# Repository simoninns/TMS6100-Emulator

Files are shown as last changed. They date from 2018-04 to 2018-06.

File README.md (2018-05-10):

## Synopsis

TMS6100 speech PHROM (PHrase Read Only Memory) hardware emulator for use with the TMS5220 Voice Synthesis Processor in an Acorn BBC Microcomputer

## Motivation

This project creates a TMS6100 speech PHROM (PHrase Read Only Memory) for use with the TMS5220 Voice Synthesis Processor in an Acorn BBC Microcomputer. Whilst it’s still possible to purchase TMS5220 ICs from sites like Ebay, the TMS6100 was a mask-programmed ROM that Acorn produced specifically for their speech upgrade and is therefore difficult and expensive to source. Instead of using the original ROM, this project uses an ATmega32U2 microcontroller to both emulate the ROM and provide the original Acorn voice sample data recorded by BBC newsreader Kenneth Kendall.

## Installation

Note: This is an Atmel Studio 7 project that can be loaded and compiled by the IDE

Please see http://www.waitingforfriday.com/?p=30 for detailed documentation about TMS6100-Emulator

The PHROM data for both the Acorn Speech System PHROM and the American TI PHROM is included in the source-code.  By default it will compile using the Acorn Speech Data.  Specifying the compiler macro PHROM_ACORN selects the Acorn PHROM and PHROM_US selects the American PHROM.  Note that the American PHROM is not generally for use with the BBC Micro and is included for experimental use (or use in other microcomputer systems).

## Author

TMS6100-Emulator is written and maintained by Simon Inns.

## License (Software)

    TMS6100-Emulator is free software: you can redistribute it and/or modify
    it under the terms of the GNU General Public License as published by
    the Free Software Foundation, either version 3 of the License, or
    (at your option) any later version.

    TMS6100-Emulator is distributed in the hope that it will be useful,
    but WITHOUT ANY WARRANTY; without even the implied warranty of
    MERCHANTABILITY or FITNESS FOR A PARTICULAR PURPOSE.  See the
    GNU General Public License for more details.

    You should have received a copy of the GNU General Public License
    along with TMS6100-Emulator. If not, see <http://www.gnu.org/licenses/>.

## License (Hardware)

Both the schematic and the PCB design of TMS6100-Emulator are covered by a Creative Commons license; as with the software you are welcome (and encouraged!) to extend, re-spin and otherwise use and modify the design as allowed by the license.  However; under the terms of the Attribution-ShareAlike 4.0 International (CC BY-SA 4.0) license you are required to release your design (or redesign) under the same license.  For details of the licensing requirements please see <https://creativecommons.org/licenses/by-sa/4.0/>

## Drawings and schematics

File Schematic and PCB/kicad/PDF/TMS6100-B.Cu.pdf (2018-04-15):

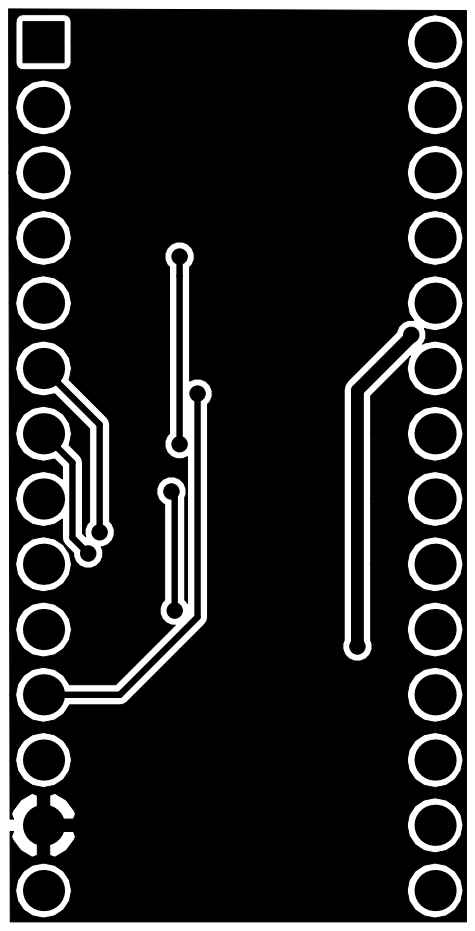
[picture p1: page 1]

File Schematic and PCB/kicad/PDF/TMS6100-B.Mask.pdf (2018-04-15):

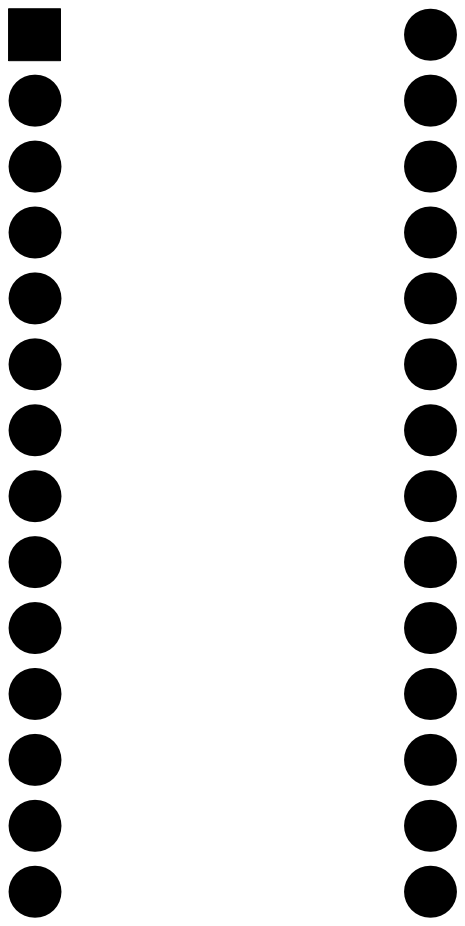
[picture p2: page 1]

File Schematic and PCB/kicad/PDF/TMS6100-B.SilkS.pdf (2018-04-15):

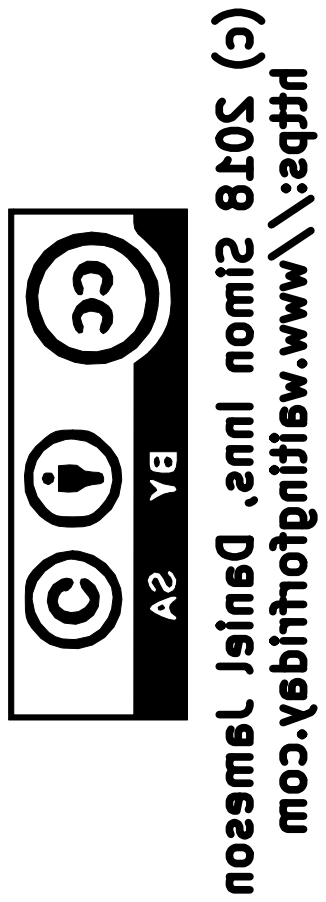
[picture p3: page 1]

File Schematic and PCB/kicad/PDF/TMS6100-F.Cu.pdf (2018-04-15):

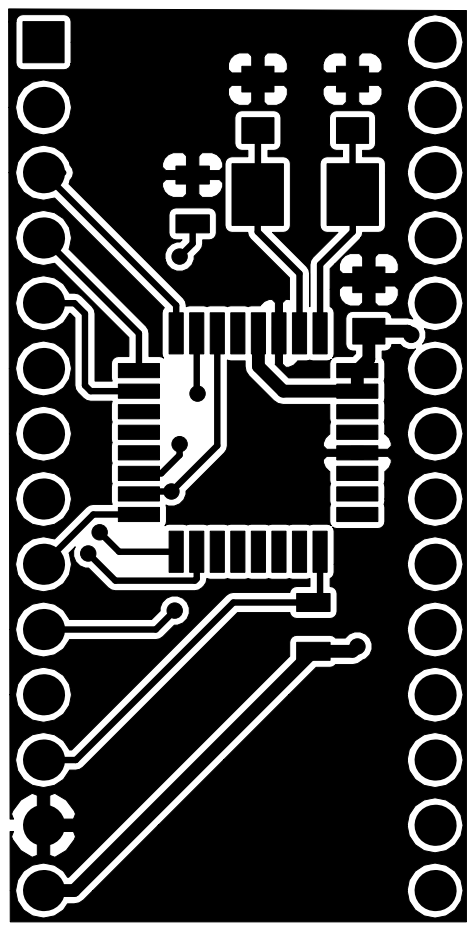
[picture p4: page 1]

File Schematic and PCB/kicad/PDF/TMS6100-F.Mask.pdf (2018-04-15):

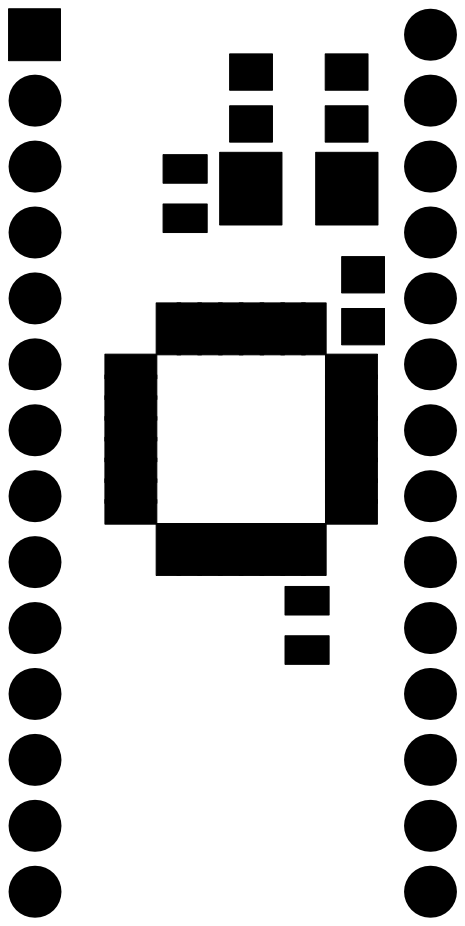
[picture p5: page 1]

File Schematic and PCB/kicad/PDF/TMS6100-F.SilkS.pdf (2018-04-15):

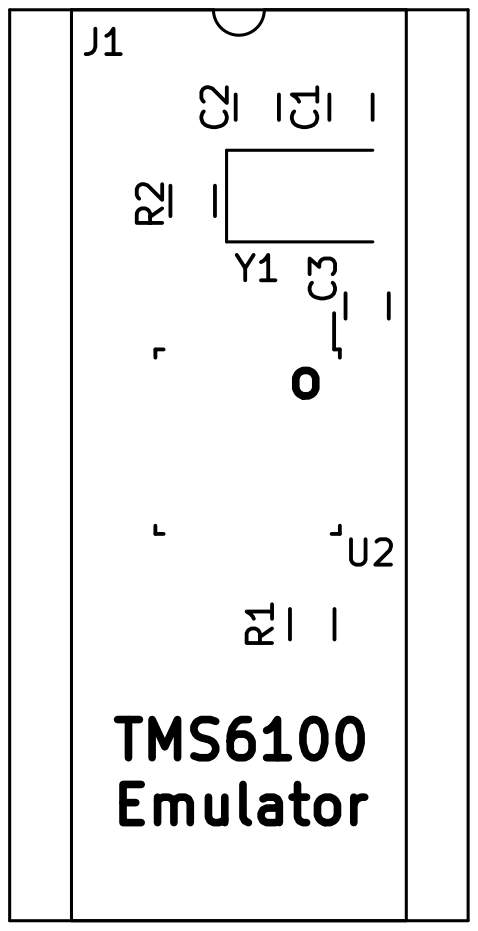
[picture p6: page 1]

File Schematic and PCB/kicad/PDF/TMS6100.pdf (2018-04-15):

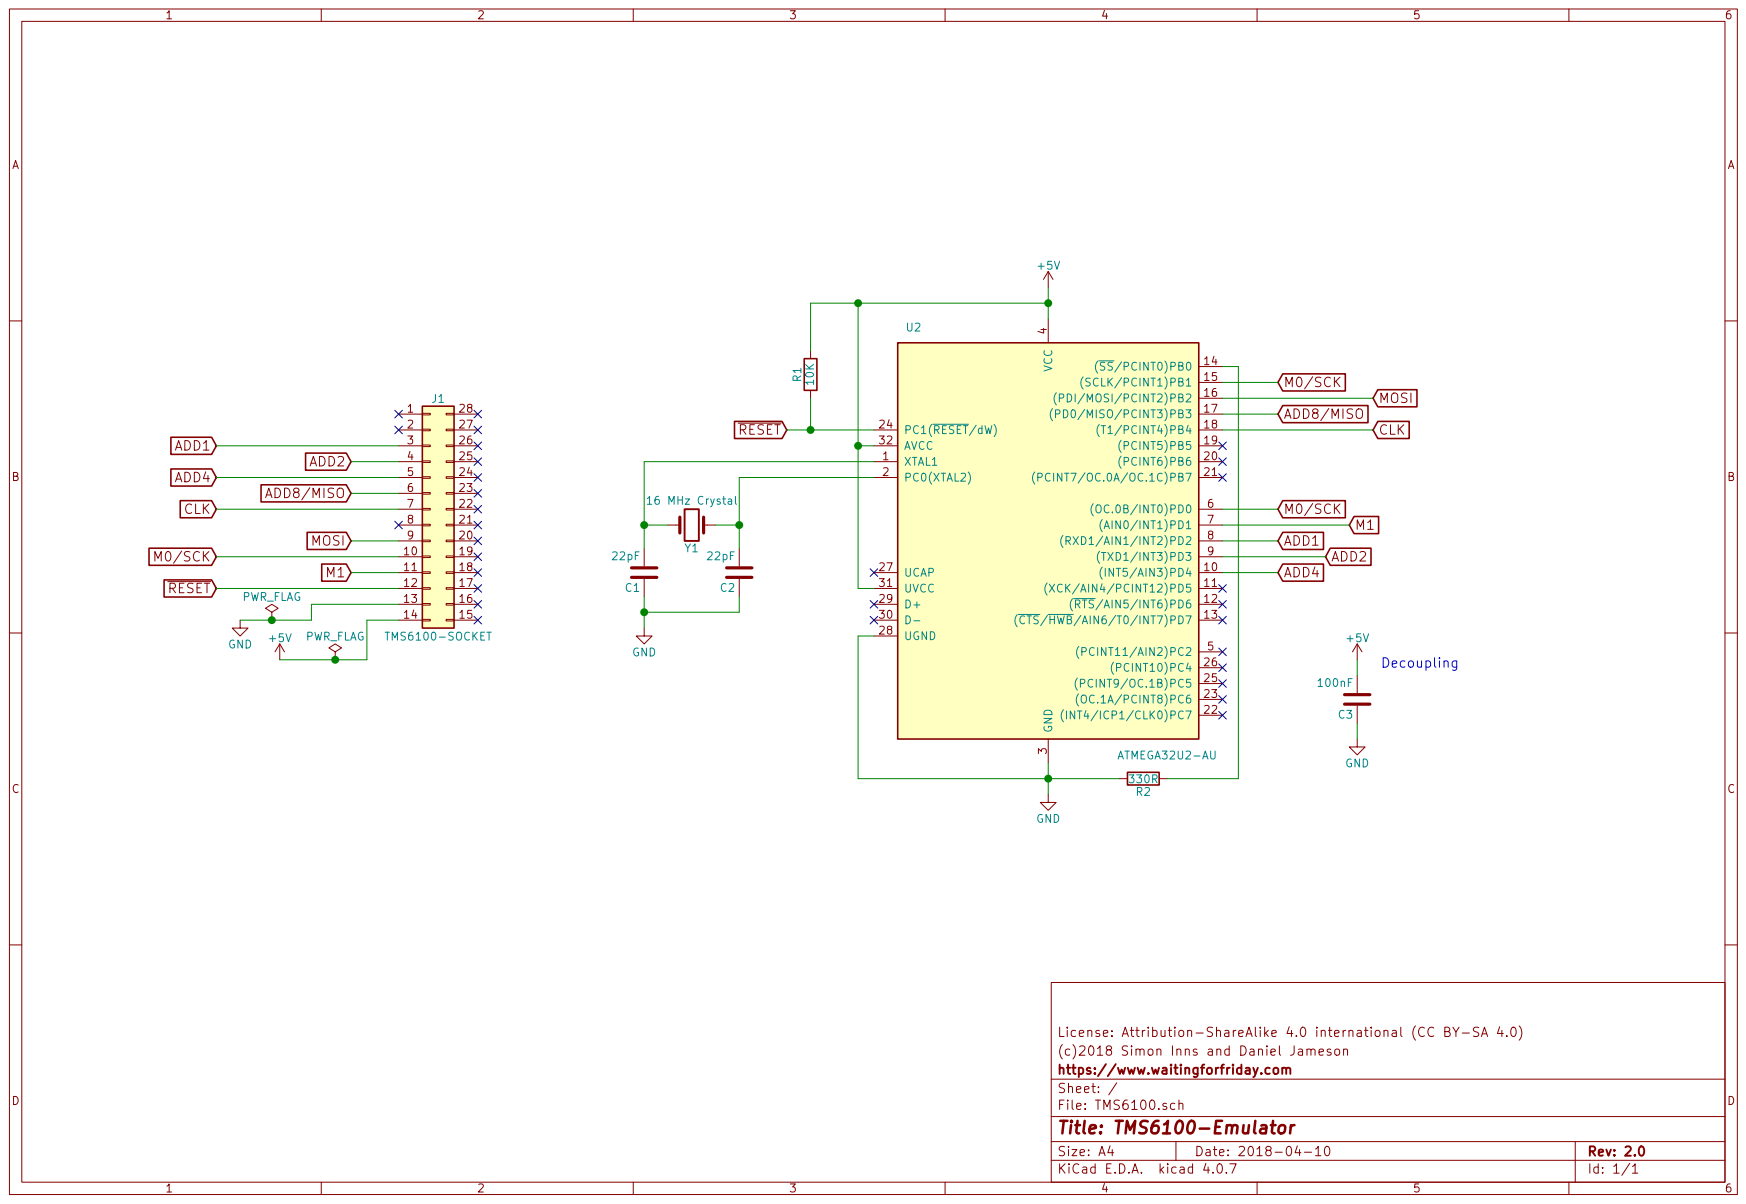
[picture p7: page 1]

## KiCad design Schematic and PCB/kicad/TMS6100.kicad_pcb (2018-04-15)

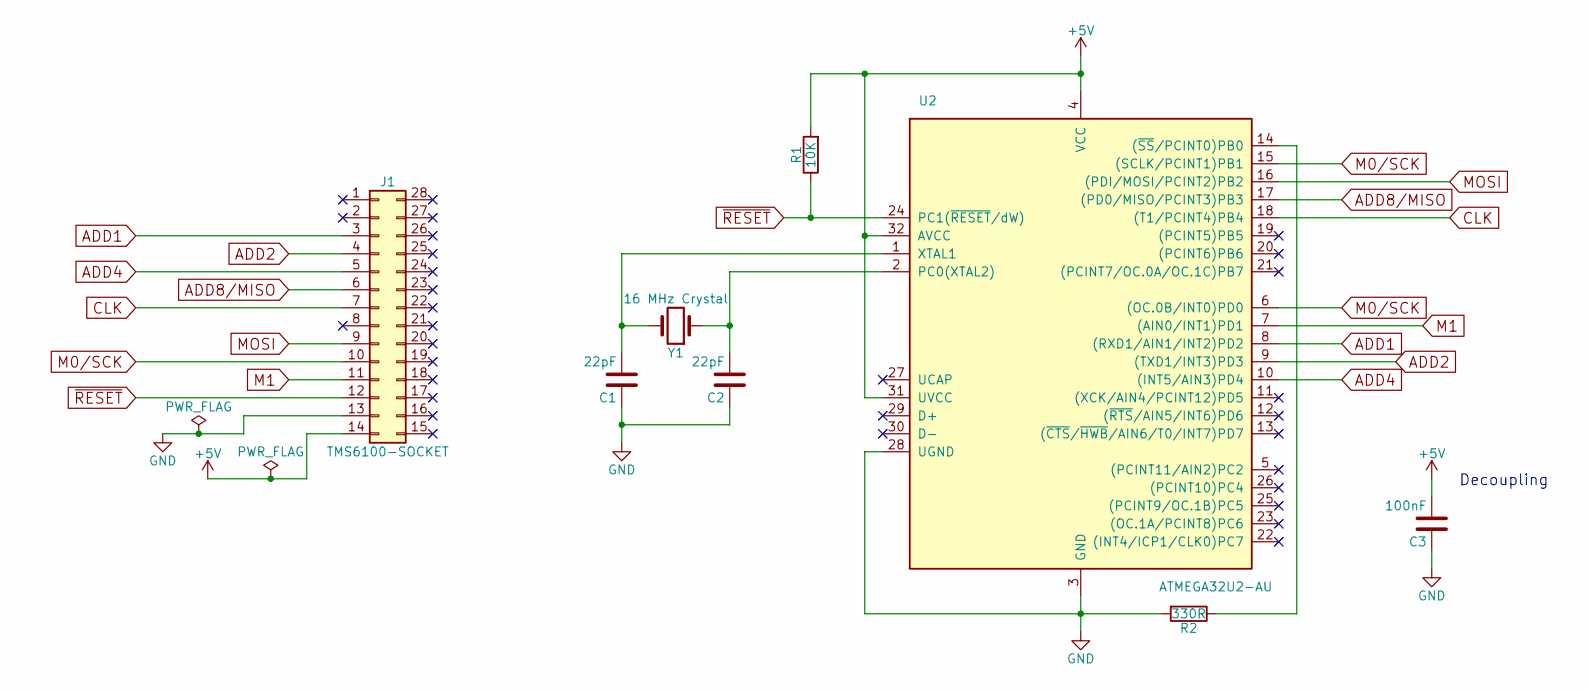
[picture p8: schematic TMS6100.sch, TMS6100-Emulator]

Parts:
C1, C2: 22pF; C_0805
C3: 100nF; C_0805
J1: TMS6100-SOCKET; DIP-28_W15.24mm_Socket
R1: 10K; R_0805
R2: 330R; R_0805
U2: ATMEGA32U2-AU; TQFP-32_7x7mm_Pitch0.8mm
Y1: 16 MHz Crystal; Crystal_SMD_5032-2pin_5.0x3.2mm

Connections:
+5V: C3.2, J1.14, R1.2, U2.4 (VCC), U2.31 (UVCC), U2.32 (AVCC)
ADD1: J1.3, U2.8 ((RXD1/AIN1/INT2)PD2)
ADD2: J1.4, U2.9 ((TXD1/INT3)PD3)
ADD4: J1.5, U2.10 ((INT5/AIN3)PD4)
ADD8/MISO: J1.6, U2.17 ((PD0/MISO/PCINT3)PB3)
CLK: J1.7, U2.18 ((T1/PCINT4)PB4)
GND: C1.1, C2.1, C3.1, J1.13, R2.2, U2.3 (GND), U2.28 (UGND)
M0/SCK: J1.10, U2.6 ((OC.0B/INT0)PD0), U2.15 ((SCLK/PCINT1)PB1)
M1: J1.11, U2.7 ((AIN0/INT1)PD1)
MOSI: J1.9, U2.16 ((PDI/MOSI/PCINT2)PB2)
unnamed: C1.2, U2.1 (XTAL1), Y1.2
unnamed: C2.2, U2.2 (PC0(XTAL2)), Y1.1
unnamed: R2.1, U2.14 ((~SS~/PCINT0)PB0)
~RESET: J1.12, R1.1, U2.24 (PC1(~RESET~/dW))

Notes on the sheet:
Decoupling

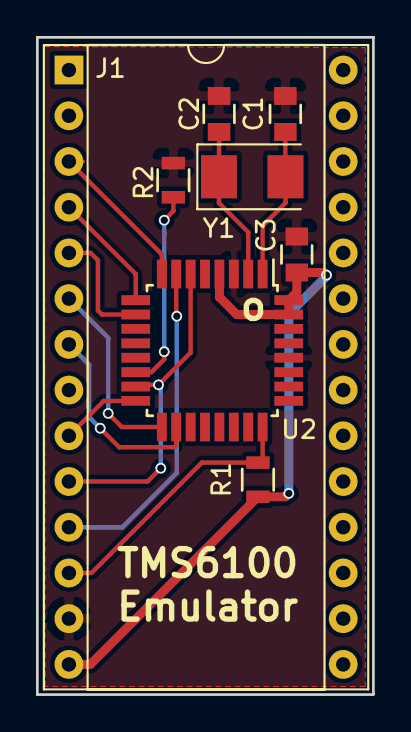
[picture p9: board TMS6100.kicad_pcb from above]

Board: 2 copper layers, 18.7 x 36.5 mm, 8 parts (0 on the bottom side), 14 nets.

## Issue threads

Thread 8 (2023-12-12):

Use on a TI-99/4A

shift838, 2023-12-12:
I am curious if this can be used on a TI-99/4A computer.

the PHROM data on the TI was split into 2 TMS6100 ICs that were piggy backed on the unit.  I have the actual dump of the PHROMs but how would I get this to work?

simoninns, 2023-12-12:
There isn't enough flash RAM available in the AVR to hold two PHROM data images; so the only way would be to piggy-back two emulator boards (or redesign one with a bigger AVR).  I've never looked into the multi-ROM operation, so I'm not sure what would happen next but, the information is most likely in the datasheet.  You would need to get this all set up with the TI-99/4A and test - the current design was specifically developed for the Acorn BBC Micro - so there are likely to be some differences in what's required.

shift838, 2023-12-12:
How did you get the BBC Micro PHROM data into the .h file?  I would need to do the same for each of my PHROM dumps.  My dumps are raw dumps for the TI.

simoninns, 2023-12-12:
The images of the data were already available online... I just used some random tool to convert them into the C language hex blocks and included them in a header file.

shift838, 2023-12-12:
can you point me to the original images of the PHROM for the bbc micro so I can compare and if you can remember what tool you used to convert.

simoninns, 2023-12-12:
The original images are just bytes in a file dumped from the PHROM... exactly the data that's included in the current project (I'm sure some googling will find other dumps of the PHROMs if you need them) - but there is nothing really to 'compare'.  As for the tool... it was a good few years ago... but writing a simple C program to read a byte stream and output hex values as text is just a few lines of code.

You can find some more detail about how the PHROM works here:

https://www.waitingforfriday.com/?p=30

shift838, 2023-12-12:
There are online converters that will also convert the binary to hex, like https://tomeko.net/online_tools/file_to_hex.php?lang=en

Also I was reading that the !CS pin has to be tied to ground since the original TMS6100 was powered by -5v.  is that correct, is that the only change that needs to happen?  Or does the circuit board for the 6100 Emulator already do that?

simoninns, 2023-12-13:
In the emulator implementation the !CS pin (13) is used to source 0V GND (look at the available schematics).  This is because the original was +5V and -5V supplied - which cannot be supported by the AVR microcontroller without additional components.

https://github.com/simoninns/TMS6100-Emulator/blob/master/Schematic%20and%20PCB/kicad/PDF/TMS6100.pdf

shift838, 2024-01-16:
what tool did you use to compile this firmware into a hex file?

shift838, 2024-01-17:
I was able to get it compiled with Atmel Studio 7.

shift838, 2024-01-18:
a few more questions:

1. Does the hex file generated already have the bootloader imbedded or do you need to write a bootloader to the ATMEGA32U2 ?
2. What programmer are you using to write the bootloader and/or hex to the ATMEGA32U2 chip?
3. If you need to update the code on the TMS6100 emulator board after it is built how are you doing that?

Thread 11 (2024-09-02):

Programming questions

shift838, 2024-09-02:
I have built the TMS6100 and want to use it for another retro computer (TI-99/4A) that actually use 2 TMS6100 piggy backed.  I have dump my ROMS for the speech and will need to program 2 TMS6100 emulator chips.

My question is I have burned a boot loader using the below command on both tms6100 emulator chips:
avrdude -vvv -c USBasp -p m32u2 -u -U flash:w:d:\speech\roms\BL_atmega32u2.hex:i

The above is a boot loader.  I then burn the appropriate speech ROM into each one:
avrdude -vvv -c USBasp -p m32u2 -u -U flash:w:d:\speech\roms\CD2325A.hex:i

replace with the second chip and issue command:
avrdude -vvv -c USBasp -p m32u2 -u -U flash:w:d:\speech\roms\CD2326A.hex:i

Both go with no issues but putting them in the TI speech synthesizer produces no speech.  I am wondering if I am doing something wrong.  Do you have the bootloader you were using in your original project?

simoninns, 2024-09-03:
The bootloader is just the default that comes with the chip, it's not required.  Make sure the circuit is getting 0V and +5V - the original chip used -5V and +5V.  See the following documentation (and compare your target circuit with the schematic):

https://www.waitingforfriday.com/?p=30

shift838, 2024-09-03:
I thought this was just a drop in replacement on original circuits and you did not have to wire up different power?

simoninns, 2024-09-03:
It's a good idea to read the documentation, especially if you are trying to do something the project was not intended for.  Let me quote the webpage :)

"Use in other microcomputers

The function of the TMS6100 is common across all types of microcomputers that use the TMS5220 chipset and the PHROM data can be easily modified to represent data other than the Acorn PHROM.  If you would like to use the emulator in machines other than the BBC Micro, care should be taken to ensure that the CS pin of the TMS6100 is tied directly to ground as the emulator relies on this for 5V power (the original chip used 5V and -5V).  Only the features required by the Acorn implementation are included in the firmware; the comments in the firmware source-code state both the supported and unsupported features, so please examine the code for detailed explanation of the implementation."

shift838, 2024-09-03:
I have read the documentation from page 1 to the end multiple times to make sure I have not missed anything.

I have also verified that pin 13 is a ground signal and pin 14 has+5v DC being supplied.

I'm not sure about the Acorn computer but for the TI the ROMs have a reversed bit order (per byte).  I have taken that in account, of course I have tried generating the hex required in both standard and reverse and both yield the same results.

With that being said, your program would it matter if the hex bits are in reverse order?

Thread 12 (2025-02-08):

Query - Methods of dumping a chip?

os144046, 2025-02-08:
I came across a VM61001 (TMS6100 for Heathkit) chip which is hard to find and doesn't seem to be available for download anywhere.

I would like to preserve it for use with your emulator and I am hoping that you can suggest a good method to pull data from the chip. Is my best bet going to be getting a vintage system that supports a TMS6100?

I have a 6502 board and a 68000, but nothing with built-in support for the chip. I also have raspberry, arduino, esp8266. Edit: and I currently have it hooked up to a TMS5100 on a breadboard.

simoninns, 2025-02-08:
You can read the chip using any 5V microcontroller, the arduino is perfect.  Simply read the chip (following the instructions for accessing in the datasheet - it's really a simple interface) and dump the data output to serial so you can record it on a PC.  Any retro PC (like the BBC Micro) that supports the chip will also be able to do the same trick, but it's probably easier to write some simple microcontroller code.

Closed 2025-02-08.

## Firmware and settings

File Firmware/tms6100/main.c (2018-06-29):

/************************************************************************
	main.c

    TMS6100 Emulator (for use with TMS5220 VSP)
    Copyright (C) 2018 Simon Inns

	This file is part of the TMS6100-Emulator.

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
	Email: simon.inns@gmail.com

************************************************************************/

// Note: The TMS6100 was mask programmed for either 1-bit or 4-bit data
// transfer.  This emulation is for use with the TMS5220 VSP which only
// supports 1-bit mode.  Therefore 4-bit data is not emulated.

// This code has only been tested for use with the TMS5220 as a phrase ROM
// (PHROM) - If you use it with another device, your millage may vary :)

// Global includes
#include <avr/io.h>
#include <avr/pgmspace.h>
#include <avr/power.h>
#include <avr/wdt.h>
#include <util/delay.h>

// Include the required PHROM data image.  Available options are:
//
// PHROM_ACORN - The Acorn Speech System PHROM data
// PHROM_US - The TI American speech PHROM data
//
#ifdef PHROM_ACORN
	// Acorn PHROM data
	#pragma message ("Using Acorn Speech System PHROM data")
	#include "romdata_acorn.h"
#elif PHROM_US
	// TI US PHROM data
	#pragma message ("Using American TI Speech System PHROM data")
	#include "romdata_us.h"
#else
	// No PHROM was defined (or an unknown PHROM)
	#pragma message ("Using Acorn Speech System PHROM data (default)")
	#include "romdata_acorn.h"
#endif

// Include the hardware mapping
#include "hardwaremap.h"

// Some useful definitions
#define FALSE	0
#define TRUE	1

// Variables for holding the current state of the TMS6100
uint32_t currentAddress;
uint8_t m0ReadyReceived;

uint8_t outputBuffer;
uint8_t outputBufferPointer;

uint8_t outputEnabled;

// Initialise the AVR hardware
void initialiseHardware(void)
{
	// Set M0 and M1 pins to input and turn off weak pull-ups
	TMS6100_M0_DDR &= ~TMS6100_M0;
	TMS6100_M1_DDR &= ~TMS6100_M1;
	
	TMS6100_M0_PORT &= ~TMS6100_M0;
	TMS6100_M1_PORT &= ~TMS6100_M1;

	// Set the address bus to input and turn off weak pull-ups
	TMS6100_ADD1_DDR &= ~TMS6100_ADD1;
	TMS6100_ADD2_DDR &= ~TMS6100_ADD2;
	TMS6100_ADD4_DDR &= ~TMS6100_ADD4;
	TMS6100_ADD8_DDR &= ~TMS6100_ADD8;
	
	TMS6100_ADD1_PORT &= ~TMS6100_ADD1;
	TMS6100_ADD2_PORT &= ~TMS6100_ADD2;
	TMS6100_ADD4_PORT &= ~TMS6100_ADD4;
	TMS6100_ADD8_PORT &= ~TMS6100_ADD8;
	
	// Set CLK to input and turn off weak pull-ups
	TMS6100_CLK_DDR &= ~TMS6100_CLK;
	TMS6100_CLK_PORT &= ~TMS6100_CLK;
	
	// Initialise the TMS6100 emulation:
	
	// Set the initial address pointer
	currentAddress = 0x00;
	
	// Initial M0 signal received flag
	// Note: this indicates if we've received the first M0 'ready' signal
	// following an M1 signal
	m0ReadyReceived = FALSE;
	
	// Initialise the output buffer
	outputBuffer = 0xFF;
	outputBufferPointer = 0;
	outputEnabled = FALSE;
	
	// Initialise the SPI pins (no longer used in this firmware)
	// (MISO configured by ADD8)
	TMS6100_MOSI_DDR &= ~TMS6100_MOSI;
	TMS6100_SCK_DDR  &= ~TMS6100_SCK;
	TMS6100_SS_DDR   &= ~TMS6100_SS;
	
	TMS6100_MOSI_PORT &= ~TMS6100_MOSI;
	TMS6100_SCK_PORT  &= ~TMS6100_SCK;
	TMS6100_SS_PORT   &= ~TMS6100_SS;
	
	// Initialise the debug pins as outputs
	// and set to off
	DEBUG0_DDR |= DEBUG0;
	DEBUG1_DDR |= DEBUG1;
	DEBUG2_DDR |= DEBUG2;
	
	DEBUG0_PORT &= ~DEBUG0;
	DEBUG1_PORT &= ~DEBUG1;
	DEBUG2_PORT &= ~DEBUG2;
}

// Function to handle the rising edge of M0
// Note: The falling edge of M0 indicates a READ DATA command
void m0SignalHandler(void) //ISR(TMS6100_M0_INT_VECT)
{
	if (m0ReadyReceived == FALSE) {
		// Show M0 handler active in debug
		DEBUG0_PORT |= DEBUG0;
		
		// This is the first M0 pulse after a M1 pulse (the 'ready' pulse)
		m0ReadyReceived = TRUE;
		
		// Get the current bank and local address
		uint32_t currentBank = (currentAddress & 0x3C000) >> 14; // 0b 0011 1100 0000 0000 0000 = 0x03C000
		uint32_t localAddress = (currentAddress & 0x3FFF); // 0b 0000 0011 1111 1111 1111 = 0x03FFF
		
		// Load the byte to be transmitted (if this is our bank)
		if (currentBank == PHROM_BANK) {
			// Load the output buffer
			outputBuffer = pgm_read_byte(&(phromData[localAddress]));
			
			// Set the ADD8 bus pin to output mode and set the pin high
			// (as this is what the original TMS6100 does)
			if (outputEnabled == FALSE) {
				TMS6100_ADD8_DDR |= TMS6100_ADD8;
				TMS6100_ADD8_PORT |= TMS6100_ADD8;
				outputEnabled = TRUE;
			}
		} else {
			outputBuffer = 0x00;
			outputBufferPointer = 0;
			
			// Set the ADD8 bus pin to input mode
			if (outputEnabled == TRUE) {
				TMS6100_ADD8_DDR &= ~TMS6100_ADD8;
				TMS6100_ADD8_PORT &= ~TMS6100_ADD8;
				outputEnabled = FALSE;
			}
		}
		
		// Reset the buffer pointer
		outputBufferPointer = 0;
		
		// Show M0 handler inactive in debug
		DEBUG0_PORT &= ~DEBUG0;
	} else {
		// Show M0 handler active in debug
		DEBUG1_PORT |= DEBUG1;
		
		// This is a data read M0 pulse
		
		// Get the current bank and local address
		uint32_t currentBank = (currentAddress & 0x3C000) >> 14; // 0b 0011 1100 0000 0000 0000 = 0x03C000
		
		// Load the byte to be transmitted (if this is our bank)
		if (currentBank == PHROM_BANK) {
			// Set the data on the output pin (so it is valid when the falling edge of M0 occurs)
			if (outputBuffer & (1 << outputBufferPointer)) TMS6100_ADD8_PORT |= TMS6100_ADD8;
			else TMS6100_ADD8_PORT &= ~TMS6100_ADD8;
		}
		
		// Increment the bit pointer
		outputBufferPointer += 1;
		
		// Show M0 handler inactive in debug
		DEBUG1_PORT &= ~DEBUG1;
	}
	
	// Check if we need to reload the output buffer
	if (outputBufferPointer == 8) {
		// Get the next byte to transmit
		currentAddress++;
				
		// Get the current bank and local address
		uint32_t currentBank = (currentAddress & 0x3C000) >> 14; // 0b 0011 1100 0000 0000 0000 = 0x03C000
		uint32_t localAddress = (currentAddress & 0x3FFF); // 0b 0000 0011 1111 1111 1111 = 0x03FFF
		
		// Load the byte to be transmitted (if this is our bank)
		if (currentBank == PHROM_BANK) {
			// Load the output buffer
			outputBuffer = pgm_read_byte(&(phromData[localAddress]));
			
			// Reset the buffer pointer
			outputBufferPointer = 0;
			
			// If the output is disabled, enable it now
			// Note: this is for the edge case where a sequence of reads
			// cross a PHROM bank boundary
			if (outputEnabled == FALSE) {
				TMS6100_ADD8_DDR |= TMS6100_ADD8;
				TMS6100_ADD8_PORT |= TMS6100_ADD8;
				outputEnabled = TRUE;
			}
		} else {
			outputBuffer = 0x00;
			outputBufferPointer = 0;
			
			// Set the ADD8 bus pin to input mode
			if (outputEnabled == TRUE) {
				TMS6100_ADD8_DDR &= ~TMS6100_ADD8;
				TMS6100_ADD8_PORT &= ~TMS6100_ADD8;
				outputEnabled = FALSE;
			}
		}
	}
}

// Function to handle the rising edge of M1
// Note: The rising edge of M1 indicates a LOAD ADDRESS command
void m1SignalHandler(void)
{
	uint32_t addressNibble = 0;
	
	// Show M1 handler active in debug
	DEBUG2_PORT |= DEBUG2;
	
	// Set the ADD8 bus pin to input mode
	if (outputEnabled == TRUE) {
		TMS6100_ADD8_DDR &= ~TMS6100_ADD8;
		TMS6100_ADD8_PORT &= ~TMS6100_ADD8;
		outputEnabled = FALSE;
	}
	
	// Read the nibble from the address bus
	if ((TMS6100_ADD1_PIN & TMS6100_ADD1)) addressNibble += 1;
	if ((TMS6100_ADD2_PIN & TMS6100_ADD2)) addressNibble += 2;
	if ((TMS6100_ADD4_PIN & TMS6100_ADD4)) addressNibble += 4;
	if ((TMS6100_ADD8_PIN & TMS6100_ADD8)) addressNibble += 8;
	
	// The current address register is 20-bits wide
	// Addresses are loaded by transferring 5 nibbles (5x 4-bits)
	// The first nibble is the least significant nibble
	
	// Shift the current address register right one nibble
	currentAddress = currentAddress >> 4;
	
	// Place the received nibble in the top of the current address register
	currentAddress |= (addressNibble << 16);
	
	// Reset the M0 ready received flag
	m0ReadyReceived = FALSE;
	
	// Show M1 handler inactive
	DEBUG2_PORT &= ~DEBUG2;
}

// Note:  The TMS6100 supports a 3rd command (INDIRECT ADDRESS) which is
// indicated by both M0 and M1 rising at the same time.  This isn't used
// by the TMS5220 VSP, so it's not implemented in this emulator.

// Main function
int main(void)
{
	// Initialise the hardware
	initialiseHardware();
	
	// Disable the watchdog timer (if set in fuses)
	MCUSR &= ~(1 << WDRF);
	wdt_disable();

	// Disable the clock divider (if set in fuses)
	clock_prescale_set(clock_div_1);
	
	// Main processing loop	
	uint8_t m0State = FALSE;
	uint8_t m1State = FALSE;
	uint8_t m0PreviousState = FALSE;
	uint8_t m1PreviousState = FALSE;
	
    while (1) {
		m0PreviousState = m0State;
		m1PreviousState = m1State;
		
		if (TMS6100_M0_PIN & TMS6100_M0) m0State = TRUE; else m0State = FALSE;
		if (TMS6100_M1_PIN & TMS6100_M1) m1State = TRUE; else m1State = FALSE;
		
		// React on the leading edge
		if (m0State == TRUE && m0PreviousState == FALSE) m0SignalHandler();
		if (m1State == TRUE && m1PreviousState == FALSE) m1SignalHandler();
	}
}

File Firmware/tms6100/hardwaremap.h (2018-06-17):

/************************************************************************
	hardwaremap.h

    Physical hardware mapping definitions for portability
    Copyright (C) 2018 Simon Inns

    This file is part of the TMS6100-Emulator.

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
    Email: simon.inns@gmail.com

    ************************************************************************/

#ifndef HARDWAREMAP_H_
#define HARDWAREMAP_H_

// Target device: ATmega32u2
// Also tested on the ATmega32u4 (Arduino Leonardo mini pro)

// Definitions for TMS6100 IO Pins --------------------------------------

// ADD1 (PD2)
#define TMS6100_ADD1_PORT	PORTD
#define TMS6100_ADD1_PIN	PIND
#define TMS6100_ADD1_DDR	DDRD
#define TMS6100_ADD1		(1 << 2)

// ADD2 (PD3)
#define TMS6100_ADD2_PORT	PORTD
#define TMS6100_ADD2_PIN	PIND
#define TMS6100_ADD2_DDR	DDRD
#define TMS6100_ADD2		(1 << 3)

// ADD4 (PD4)
#define TMS6100_ADD4_PORT	PORTD
#define TMS6100_ADD4_PIN	PIND
#define TMS6100_ADD4_DDR	DDRD
#define TMS6100_ADD4		(1 << 4)

// ADD8 (PB3/MOSI)
#define TMS6100_ADD8_PORT	PORTB
#define TMS6100_ADD8_PIN	PINB
#define TMS6100_ADD8_DDR	DDRB
#define TMS6100_ADD8		(1 << 3)

// M0 (PD0/INT0)
#define TMS6100_M0_PORT		PORTD
#define TMS6100_M0_PIN		PIND
#define TMS6100_M0_DDR		DDRD
#define TMS6100_M0			(1 << 0)
#define TMS6100_M0_INT		INT0
#define TMS6100_M0_INT_VECT	INT0_vect
#define TMS6100_M0_ISC0		ISC00
#define TMS6100_M0_ISC1		ISC01
#define TMS6100_M0_INTF		INTF0

// M1 (PD1/INT1)
#define TMS6100_M1_PORT		PORTD
#define TMS6100_M1_PIN		PIND
#define TMS6100_M1_DDR		DDRD
#define TMS6100_M1			(1 << 1)
#define TMS6100_M1_INT		INT1
#define TMS6100_M1_INT_VECT	INT1_vect
#define TMS6100_M1_ISC0		ISC10
#define TMS6100_M1_ISC1		ISC11
#define TMS6100_M1_INTF		INTF1

// CLK (PB4) - Not currently used by the emulator as we use
// the SPI module to asynchronously time data based on the 
// M0 pulses (which has the effect of making the data in sync
// with the clock).
#define TMS6100_CLK_PORT	PORTB
#define TMS6100_CLK_PIN		PINB
#define TMS6100_CLK_DDR		DDRB
#define TMS6100_CLK			(1 << 4)

// Definitions for SPI pins ---------------------------------------------

// MISO - This is ADD8 defined above 

// MOSI (PB2)
#define TMS6100_MOSI_PORT	PORTB
#define TMS6100_MOSI_PIN	PINB
#define TMS6100_MOSI_DDR	DDRB
#define TMS6100_MOSI		(1 << 2)

// SCK (PB1)
#define TMS6100_SCK_PORT	PORTB
#define TMS6100_SCK_PIN		PINB
#define TMS6100_SCK_DDR		DDRB
#define TMS6100_SCK			(1 << 1)

// !SS (PB0)
#define TMS6100_SS_PORT		PORTB
#define TMS6100_SS_PIN		PINB
#define TMS6100_SS_DDR		DDRB
#define TMS6100_SS			(1 << 0)

// Definitions for debug pins -------------------------------------------

// Note: These pins are used for development and are not present
// on the production version of the PCB

#define DEBUG0_PORT	PORTD
#define DEBUG0_PIN	PIND
#define DEBUG0_DDR	DDRD
#define DEBUG0		(1 << 5)

#define DEBUG1_PORT	PORTD
#define DEBUG1_PIN	PIND
#define DEBUG1_DDR	DDRD
#define DEBUG1		(1 << 6)

#define DEBUG2_PORT	PORTD
#define DEBUG2_PIN	PIND
#define DEBUG2_DDR	DDRD
#define DEBUG2		(1 << 7)

#endif /* HARDWAREMAP_H_ */

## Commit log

2018-04-10 Initial commit of project files (firmware and eagle cad)
    [TMS6100 Emulator 1_3.brd, TMS6100 Emulator 1_3.sch]
2018-04-10 Corrected source files - fixed header information
    [hardwaremap.h, main.c]
2018-04-10 kicad schematics
    [TMS6100.kicad_pcb, TMS6100.sch]
2018-04-10 Updated schematic and included fixes
    I've modified the labels into global labels and corrected PB0. Components and nodes have been space out to make the diagram clearer. Power connections are now pointing in the correct directions. Also added sheet labels. Header is still missing from diagram.
    [TMS6100.sch]
2018-04-12 Fix ERC, also socket
    [TMS6100.sch]
2018-04-12 Correct component for socket, footprints mapped
    [TMS6100.sch]
2018-04-14 V1 PCB Layout
    [TMS6100.kicad_pcb, TMS6100.sch]
2018-04-14 Silkscreen fixed
    [TMS6100.kicad_pcb]
2018-04-14 Vias fixed
    [TMS6100.kicad_pcb]
2018-04-14 reverse ground plane added
    [TMS6100.kicad_pcb]
2018-04-15 Additional changes to schematic and PCB
    Added 'R' to 330R resistor
    Added PCB edge cuts and rearranged text markers into boundaries
    Orientated resistors the same for quicker assembly
    Added URL for WFF
    Added additional marker for TQPF visual orientation
    Removed unnecessary vias around reset pull up resistor
    [TMS6100.kicad_pcb, TMS6100.sch]
2018-04-15 Added gerbers and PDF files, removed Eagle files
    [TMS6100 Emulator 1_3.brd, TMS6100 Emulator 1_3.sch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]
2018-05-01 Added CC license to KiCAD files
2018-05-07 Fixed issue where fuse setting prevented emulator from functioning
    Added override for WDT and clock div 8 fuse settings (now works with stock ATmega32u2 without the need to reprogram fuses).
    Also fixed build environment to compile in release mode rather than debug (with -O1 optimisation).
    [main.c]
2018-06-17 Removed SPI, replaced with bit-banging method
    The use of the SPI module has been removed to allow better control over the READ DATA command signals. The READ DATA command is now performed purely using interrupts on the M0 signal.
    [hardwaremap.h, main.c]
2018-06-17 Added code to float ADD8 when PHROM's bank isn't selected. Code currently shows timing issues
    READ DATA command is not currently 100% successful. Emulator is causing sample corruption.
    [main.c]
2018-06-17 Removed Interrupt Service Requests to improve response speeds
2018-06-17 Revert "Non-functioning build - access time from M0 control still to slow (needs to be <2us)"
    This reverts commit 3a050840b85f405825ca27e36f8b6f29d2051f4c.
    [hardwaremap.h, main.c]
2018-06-17 Added back in SPI code - timing of data output on ADD8 is not correct
    The timing possible without using SPI is not fast enough for the primary transfer. Remerging SPI code. Idea will be to use SPI when bank is valid and then use interrupts to track M0 during non-local bank reads (to assure boundaries are crossed correctly between PHROMs).
    [main.c]
2018-06-18 Interim check in with SPI re-enabled
    Not currently working; first read data is missing a leading 0
    [main.c]
2018-06-23 Better logic trace comparison to original PHROM, but still non-functional
2018-06-28 New working version without interrupts or SPI - with more accurate timing
2018-06-28 Emulator now correctly supports 'stacked' PHROMs allowing multiple PHROMs to be used at once
    [main.c]

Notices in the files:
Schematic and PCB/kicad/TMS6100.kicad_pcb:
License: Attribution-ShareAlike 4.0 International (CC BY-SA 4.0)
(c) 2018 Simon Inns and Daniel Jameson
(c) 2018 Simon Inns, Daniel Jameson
